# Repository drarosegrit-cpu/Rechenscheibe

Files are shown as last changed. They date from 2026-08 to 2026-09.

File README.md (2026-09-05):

# 🧭 Nautische Rechenscheibe & Taktik-Suite V1.0 – JPK 1080 (*TRUE GRIT*, GER 7447)

Professionelles, analog-digitales Regatta-, Navigations- und Taktiksystem für die Yacht **JPK 1080 (*TRUE GRIT*, GER 7447)**.  
Dieses System verbindet die offiziellen **ORC-VPP-Polardaten** (ORC International / Club, Run-ID `249116`) mit:
1. Einer **doppelseitigen $\varnothing 180\,\text{mm}$ Sandwich-Rechenscheibe** mit integriertem **TackingMaster-Taktikring**, normierten ORC-Polaren (Weg A), echten AWA-Fasskreisbögen und zirkularem Rechenschieber.
2. Einer **vollständigen Fertigungssuite** mit 3D-Druck-Modellen (STL) und hochpräzisen Laser-CAM-Vektordateien (SVG).
3. Einem **digitalen Taktik-Bordcomputer** (`tactical_advisor.py`) mit Einzelsegelanalyse und Isochronen-Routenoptimierer (`route_optimizer.py`).

---

## 📑 Inhaltsverzeichnis
1. [Systemübersicht & Mechanische Architektur (180 mm Sandwich-Kassette)](#-systemübersicht--mechanische-architektur)
2. [Vorderseite (Seite A): Taktikring & Normierte Polaren (Weg A)](#-vorderseite-seite-a-taktikring--normierte-polaren-weg-a)
3. [Rückseite (Seite B): Zirkularer Rechenschieber & Sinus-Skala (S-Skala)](#-rückseite-seite-b-zirkularer-rechenschieber--sinus-skala)
4. [Hardware-Fertigungsanleitung (3D-Druck & Lasergravur)](#-hardware-fertigungsanleitung)
5. [Software-Suite & CLI-Bedienung](#-software-suite--cli-bedienung)
6. [Taktisches Handbuch für den Regatta-Einsatz](#-taktisches-handbuch-für-den-regatta-einsatz)
7. [Dateistruktur des Repositories](#-dateistruktur-des-repositories)

---

## 📐 Systemübersicht & Mechanische Architektur

Die Rechenscheibe basiert auf einem robusten **$\varnothing 180\,\text{mm}$ Sandwich-Kassettensystem**, das für harte Hochsee- und Regattabedingungen im Cockpit entwickelt wurde.

```
                  EXPLOSIONSDARSTELLUNG DER 180 mm KASSETTE
                  
       [ 6x M3 Senkschrauben auf Teilkreis Ø 176 mm ]
                            │
                            ▼
     ┌──────────────────────────────────────────────────────────┐
     │  GEHÄUSE-DECKEL (STATOR VORDERSEITE)                     │  Ø 180 mm
     │  360° Kompassrose graviert · Sichtfenster Ø 150 mm       │  Dicke: 2.2 mm
     └──────────────────────────────────────────────────────────┘
                            │
                            ▼
     ┌──────────────────────────────────────────────────────────┐
     │  MITTELSCHEIBE (DOPPELSEITIGER ROTOR)                    │  Ø 150 mm (Rumpf)
     │  • Seite A: TackingMaster-Taktik & Polaren (Weg A)       │  Ø 172 mm (Führungsfeder)
     │  • Seite B: Log-Skala C & Sinusskala S                   │  Ø 186 mm (4 Daumen-Tabs)
     └──────────────────────────────────────────────────────────┘
                            ▲
                            │  [ Axialspiel: 0.4 mm · Radialspiel: 0.5 mm ]
                            │
     ┌──────────────────────────────────────────────────────────┐
     │  GEHÄUSE-BODEN (STATOR RÜCKSEITE)                        │  Ø 180 mm
     │  Umlaufende Führungsnut (Ø 173 mm x 2.4 mm)              │  Dicke: 4.0 mm
     │  Logarithmische Skala D graviert                         │
     └──────────────────────────────────────────────────────────┘
                            │
                            ▼
     ┌──────────────────────────────────────────────────────────┐
     │  ZENTRALZEIGER & ACHSPIN                                 │  Länge: 85 mm
     │  Acryl-Zeigerarm mit Ratio-Skala · Formschlüssiger Bolzen│  Pin: Ø 3.0 mm
     └──────────────────────────────────────────────────────────┘
```

### Mechanische Spezifikationen
* **Außendurchmesser:** $180.0\,\text{mm}$
* **Sichtfenster / Drehscheiben-Durchmesser:** $150.0\,\text{mm}$
* **Bedienung:** 4 gerändelte Daumen-Tabs an der Drehscheibe (protrudieren auf $\varnothing 186.0\,\text{mm}$, je $15^\circ$ Bogenbreite bei $45^\circ, 135^\circ, 225^\circ, 315^\circ$).
* **Führungssystem:** Feder-Nut-Führung ($\varnothing 172.0\,\text{mm}$ Federring am Rotor greift in $\varnothing 173.0\,\text{mm} \times 2.4\,\text{mm}$ Nut im Boden) – garantiert absolut spielfreien, seidenweichen Lauf ohne Verkanten.
* **Verschraubung:** 6 symmetrische $M3$-Senkkopfschrauben auf Teilkreis $\varnothing 176.0\,\text{mm}$.
* **Zentraler Zeigerarm:** $85\,\text{mm}$ transparenter Acrylzeiger mit radialer roter Peilkante, gravierter Ratio-Skala ($0.0$ bis $1.2$) und Peilspitze zur äußeren Stator-Kompassrose.

---

## ⛵ Vorderseite (Seite A): Taktikring & Normierte Polaren (Weg A)

Die Vorderseite vereint die Funktionalität des bekannten **TackingMaster-Regattarechners** mit den hochpräzisen **ORC-Geschwindigkeitspolaren** der JPK 1080.

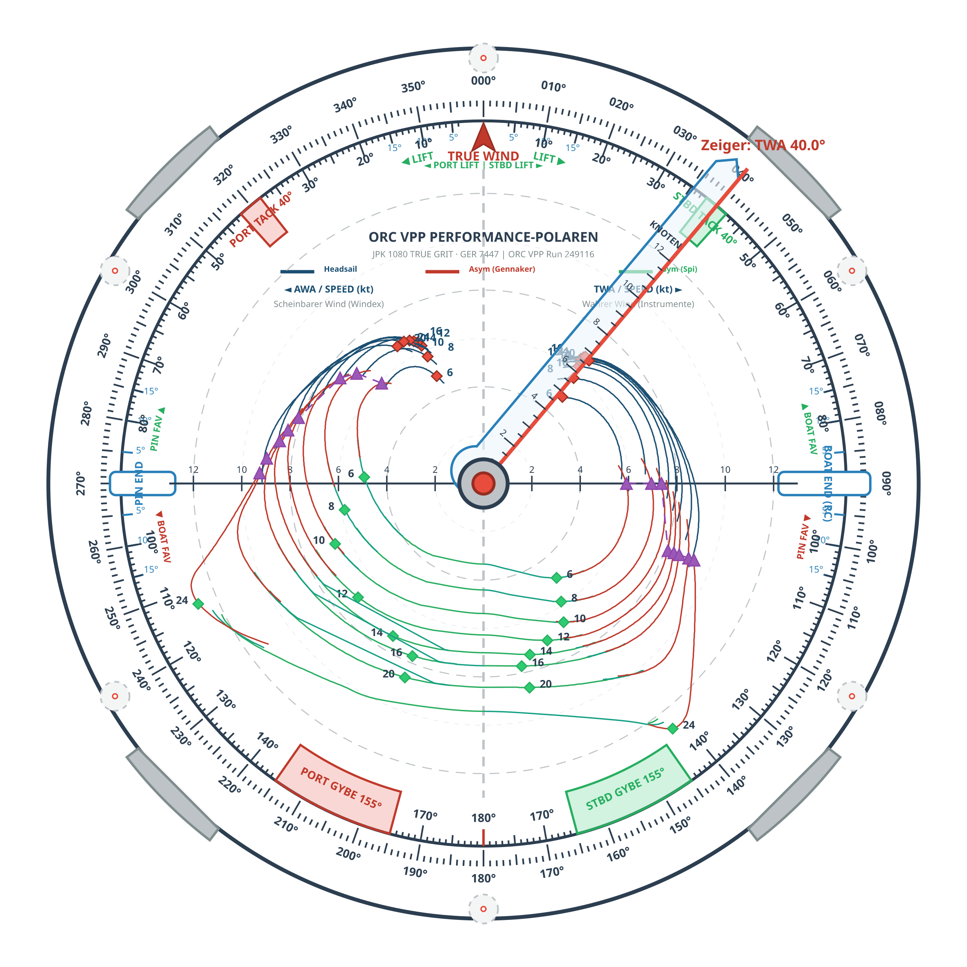
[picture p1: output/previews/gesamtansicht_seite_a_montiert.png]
Montierte Gesamtansicht Seite A


### 1. Der äußere Stator-Kompassring ($\varnothing 150$ bis $\varnothing 180\,\text{mm}$)
* Vollständige **$360^\circ$-Kompassrose** mit $1^\circ$-Feinteilung, $5^\circ$-Teilung und $10^\circ$-Beschriftung.
* Bleibt starr am Gehäuse ausgerichtet; dient zur Peilung von Windrichtung ($TWD$), Kurs über Grund ($COG$) und Landmarken.

### 2. Der integrierte TackingMaster-Taktikring (Rotor-Rand $\varnothing 132$ bis $\varnothing 150\,\text{mm}$)
* **TRUE WIND Index (12 Uhr):** Markanter roter Pfeil zum Ausrichten der Drehscheibe auf die aktuelle Wahre Windrichtung ($TWD$).
* **Winddreher-Skalen (Shift / Lift):**  
  $\pm 5^\circ, \pm 10^\circ, \pm 15^\circ$ Skalierung zu beiden Seiten des Windpfeils. Zeigt sofort, ob ein Winddreher ein **LIFT** (Höhe laufen) oder ein **HEADER** (Abfallen) auf dem aktuellen Bug ist.
* **TACK-Wendewinkel-Sektoren:**  
  Farbcodierte Zonen für Am-Wind-Kurse von **$38^\circ$ bis $42^\circ$** (Grün = Steuerbordbug / Starboard Tack, Rot = Backbordbug / Port Tack). Zeigt direkt den neuen Kurs nach der Wende an.
* **START LINE BIAS System ($\pm 90^\circ$ zur Windachse):**  
  * Eingezeichnete Peilmarken bei $+90^\circ$ (**Boat End / Startschiff**) und $-90^\circ$ (**Pin End / Starttonne**).
  * Bias-Skalen mit $\pm 5^\circ, \pm 10^\circ, \pm 15^\circ$ Abweichung: Ermöglicht die sekundenschnelle Bestimmung des bevorteilten Startlinien-Endes.
* **GYBE-Halsenwinkel-Sektoren:**  
  Farbcodierte Zonen für Vorwind-Kurse von **$145^\circ$ bis $165^\circ$** (Target VMG Gybe Angle bei $155^\circ$).

### 3. Normierte ORC-Geschwindigkeitspolaren (Weg A, $L = 64\,\text{mm}$)
* **Windpol im geometrischen Zentrum $(0,0)$:**  
  Der wahre Windvektor entspringt direkt im Drehpunkt der Scheibe.
* **Basislinie:** Rote Vertikallinie vom Windpol $(0,0)$ nach unten zum Gegenpol $P_1(180^\circ)$ bei $(0, -64\,\text{mm})$.
* **8 Windgeschwindigkeiten:** Kurven für $6, 8, 10, 12, 14, 16, 20, 24\,\text{kt}$ True Wind Speed ($TWS$).
* **Physikalische Normierung:** Der Radius entspricht dem Geschwindigkeitsverhältnis $\text{Ratio} = \frac{V_{BS}}{TWS}$.
* **VMG-Targets:**  
  * Rote Rauten: Optimale Am-Wind-Punkte ($VMG_{upwind}$ Beat Angles zwischen $42.3^\circ$ und $40.7^\circ$).
  * Grüne Rauten: Optimale Vorwind-Punkte ($VMG_{downwind}$ Run Angles zwischen $142^\circ$ und $165^\circ$).
* **Segel-Crossover (Jib vs. Asymmetrischer Gennaker):**  
  Violette Dreiecke und gestrichelte Grenzlinie markieren exakt den wahren Windwinkel ($TWA$), bei dem das Setzen des Gennakers schneller ist als die Genua/Fock.
* **Echte AWA-Fasskreisbögen:**  
  Kreisbögen durch Windpol $(0,0)$ und $P_1(180^\circ)$ für $AWA = 25^\circ, 30^\circ, 35^\circ, 40^\circ, 45^\circ, 50^\circ, 60^\circ, 75^\circ, 90^\circ, 110^\circ, 135^\circ, 155^\circ$. Ermöglichen die sofortige Ablesung des scheinbaren Windes ohne Vektorkonstruktion.

---

## 🔢 Rückseite (Seite B): Zirkularer Rechenschieber & Sinus-Skala

Die Rückseite verwandelt die Rechenscheibe in einen hochpräzisen Navigationsrechner zur Lösung von Multiplikation, Division, Weg-Zeit-Geschwindigkeit und Winddreiecks-Trigonometrie.

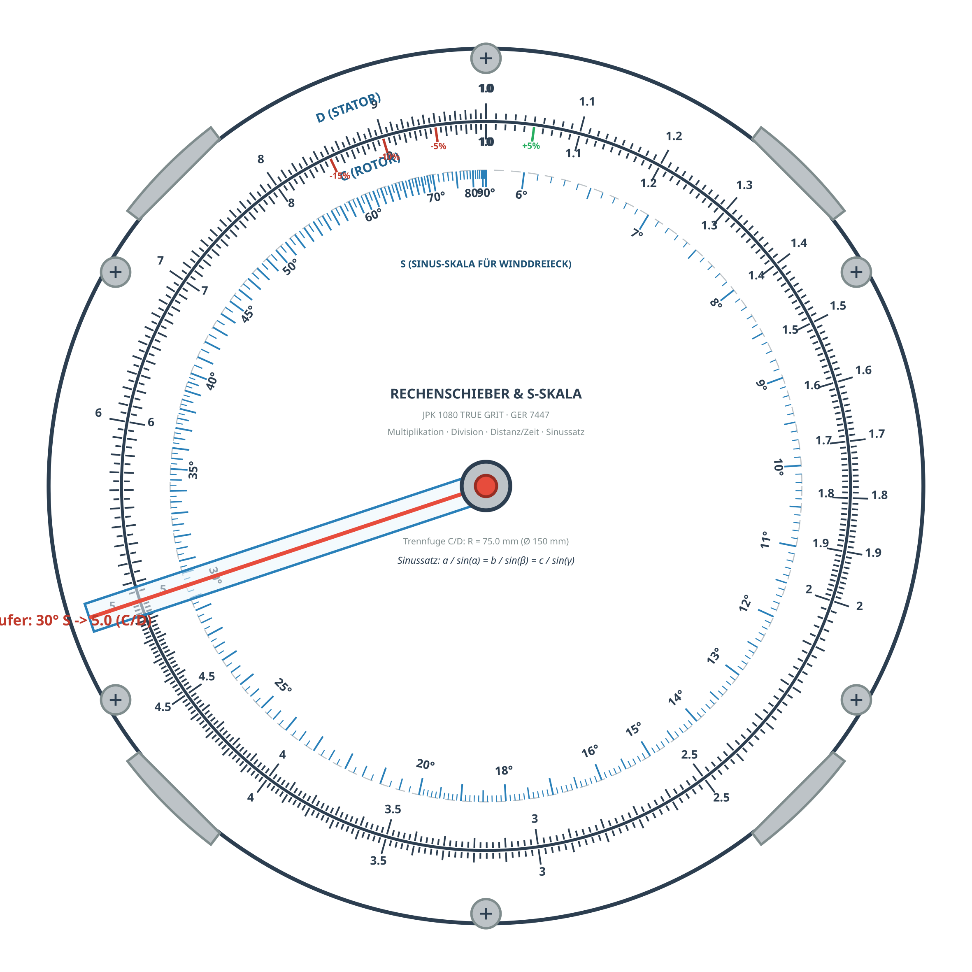
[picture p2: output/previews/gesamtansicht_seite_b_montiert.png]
Montierte Gesamtansicht Seite B


### 1. Die Skalenanordnung
* **D-Skala (Stator / Fester Außenring):**  
  Logarithmische Grundskala von $1.0$ bis $10.0$ entlang des Radius $75.5\,\text{mm}$ bis $82.0\,\text{mm}$.
* **C-Skala (Rotor / Drehscheibe):**  
  Identische logarithmische Skala von $1.0$ bis $10.0$ entlang des Radius $74.5\,\text{mm}$ nach innen.
* **Haarfeine Trennfuge bei $R = 75.0\,\text{mm}$:**  
  C- und D-Skala gleiten unmittelbar aneinander vorbei, was parallaxenfreies Ablesen ermöglicht.
* **S-Skala (Sinusskala bei $R = 48.0\,\text{mm}$):**  
  Logarithmische Teilung für Winkel von $6^\circ$ bis $90^\circ$ gemäss $\theta = 360^\circ \cdot \log_{10}(10 \cdot \sin\alpha)$.
* **Performance-Nonius (bei der $1.0$-Marke):**  
  Farbige Marken für $-15\%, -10\%, -5\%$ (Rot) und $+5\%$ (Grün) erlauben den schnellen Soll/Ist-Vergleich der Bootsgeschwindigkeit.

### 2. Rechenbeispiele

#### A. Bootsgeschwindigkeit aus Ratio berechnen ($\text{Ratio} \times TWS = V_{BS}$)
1. Lies auf Seite A an der Zeigerkante die Ratio ab (z. B. **$0.54$** bei $16\,\text{kt}$ Wind auf $TWA = 110^\circ$).
2. Drehe die Scheibe um: Stelle die **$1.0$** der C-Skala (Rotor) auf die **$0.54$** (bzw. $5.4$) der D-Skala (Stator).
3. Suche auf der C-Skala den Windwert **$1.6$** ($16\,\text{kt}$).
4. Lies auf der D-Skala direkt das Ergebnis ab: **$8.64\,\text{kt}$** Targets-Speed!

#### B. Distanz- und Fahrzeitberechnung ($\text{Distanz} = \text{Speed} \times \text{Zeit}$)
* Stelle die $1.0$ auf die Bootsgeschwindigkeit in Knoten.
* Lies für jede Fahrzeit in Stunden (C-Skala) direkt die Seemeilen (D-Skala) ab.

#### C. Lösung des Winddreiecks über die S-Skala (Sinussatz)
Im Winddreieck gilt:
$$\frac{V_{BS}}{\sin(\delta)} = \frac{AWS}{\sin(TWA)} = \frac{TWS}{\sin(AWA)}$$
Durch Kopplung der Sinusskala mit den logarithmischen Skalen lassen sich scheinbarer Windwinkel ($AWA$) und wahrer Windwinkel ($TWA$) rein mechanisch ineinander umrechnen.

---

## 🛠️ Hardware-Fertigungsanleitung

Alle Fertigungsdateien wurden mit sub-millimetergenauen Toleranzen erzeugt.

### 1. 3D-Druck (Dateien in `output/stl/`)

| Dateiname | Bauteil | Abmessungen | Empfohlenes Material |
| :--- | :--- | :--- | :--- |
| [`gehaeuse_deckel_180mm.stl`](output/stl/gehaeuse_deckel_180mm.stl) | Gehäuse-Deckel (Stator A) | $\varnothing 180 \times 2.2\,\text{mm}$, Fenster $\varnothing 150\,\text{mm}$ | PETG / ASA / PLA-CF |
| [`gehaeuse_boden_180mm.stl`](output/stl/gehaeuse_boden_180mm.stl) | Gehäuse-Boden (Stator B) | $\varnothing 180 \times 4.0\,\text{mm}$, Nut $\varnothing 173 \times 2.4\,\text{mm}$ | PETG / ASA / PLA-CF |
| [`mittelscheibe_rotor_180mm.stl`](output/stl/mittelscheibe_rotor_180mm.stl) | Rotor-Drehscheibe | $\varnothing 150/\varnothing 172/\varnothing 186 \times 2.0\,\text{mm}$ | PETG / Weiß matt |
| [`zentralzeiger_lineal.stl`](output/stl/zentralzeiger_lineal.stl) | Peilzeiger | Länge $85\,\text{mm}$, Breite $7\,\text{mm}$, Dicke $1.5\,\text{mm}$ | Transparentes PETG / Resin |
| [`achspin_mittelbolzen.stl`](output/stl/achspin_mittelbolzen.stl) | Zentraler Achsbolzen | Schaft $\varnothing 3.0 \times 7.2\,\text{mm}$, Kopf $\varnothing 9.0\,\text{mm}$ | PETG / Nylon / Messing |

#### Druckparameter-Empfehlung
* **Schichthöhe:** $0.12\,\text{mm}$ bis $0.16\,\text{mm}$
* **Wandlinien (Perimeters):** Mindestens 4 Linien
* **Infill:** $100\%$ für verzugsfreie Planlage
* **Oberflächen-Glätten (Ironing):** Auf allen Deckschichten aktivieren, um eine spiegelglatte Basis für die Skalengravur zu erhalten.

### 2. Laserschneiden & Vektorgravur (Dateien in `output/svg/`)

Die SVG-Dateien sind 1:1 im Millimeter-Maßstab für moderne CAM- und Lasersoftware (LightBurn, RDWorks, Glowforge, Trotec JobControl) vorbereitet:

| Dateiname | Funktion | Farben & Ebenen |
| :--- | :--- | :--- |
| [`laser_seite_a_rotor_vorderseite.svg`](output/svg/laser_seite_a_rotor_vorderseite.svg) | Front Rotor (Polaren & Taktik) | Rot = Schnitt, Schwarz/Farbig = Gravur |
| [`laser_seite_a_deckel_kompassrose.svg`](output/svg/laser_seite_a_deckel_kompassrose.svg) | Stator Deckel ($360^\circ$ Rose) | Rot = Schnitt (Ring & 6x M3), Schwarz = Gravur |
| [`laser_seite_b_rotor_rueckseite.svg`](output/svg/laser_seite_b_rotor_rueckseite.svg) | Back Rotor (C- & S-Skala) | Rot = Schnitt, Schwarz = Gravur |
| [`laser_seite_b_boden_d_skala.svg`](output/svg/laser_seite_b_boden_d_skala.svg) | Stator Boden (D-Skala) | Rot = Schnitt (Ring & 6x M3), Schwarz = Gravur |
| [`laser_zentralzeiger.svg`](output/svg/laser_zentralzeiger.svg) | Acryl-Zeigerarm mit Skala | Rot = Konturschnitt, Schwarz = Ratio-Teilung |

#### Laser-Farbstandard
* **Rot (`#FF0000`, Strichstärke $0.15\,\text{mm}$):** Vektorschnitt (Cut Lines).
* **Schwarz (`#000000`, Strichstärke $0.25\,\text{mm}$):** Feine Vektorgravur (Skalenstriche & Beschriftungen).
* **Buntfarben:** Akzent-Gravuren (Grün `#27AE60`, Rot `#C0392B`, Blau `#2980B9`, Violett `#8E44AD`).

---

## 💻 Software-Suite & CLI-Bedienung

### 1. Alles auf Knopfdruck generieren
```bash
python3 rechenscheibe.py --all
```
Erzeugt alle 5 STL-Dateien, alle 5 SVG-Laserdateien und alle hochauflösenden 300-DPI-PNG-Vorschauen in einem einzigen Durchlauf.

### 2. Gezielte Einzelausführung
```bash
# Nur 3D-Druck-Modelle erzeugen
python3 rechenscheibe.py --stl

# Nur Laser-SVG-Dateien erzeugen
python3 rechenscheibe.py --svg

# Vorschau mit benutzerdefiniertem Zeigerwinkel rendern (z. B. TWA 65°)
python3 rechenscheibe.py --preview --twa 65.0 --dpi 300
```

### 3. Taktischer Regattacomputer (`tactical_advisor.py`)
```bash
python3 tactical_advisor.py --hdg 215 --twd 340 --tws 14
```
Berechnet Soll-Bootsgeschwindigkeit, Krängungswinkel und Segelvergleich (Jib vs. Gennaker) für die eingegebenen Umweltbedingungen.

### 4. Regattakurs-Optimierer (`route_optimizer.py`)
```bash
python3 route_optimizer.py --gpx data/Kursdaten.gpx --twd 340 --tws 14
```

---

## 🏁 Taktisches Handbuch für den Regatta-Einsatz

### Phase 1: Vor dem Start (Startlinien-Bias)
1. Fahre die Startlinie entlang oder peile die Linie mit dem Handpeilkompass (z. B. Kurs $075^\circ$ von Pin zu Schiff).
2. Drehe den Rotor so, dass der rote **TRUE WIND Pfeil** auf die vor dem Start gemessene mittlere Windrichtung ($TWD$, z. B. $345^\circ$) auf der Gehäuse-Kompassrose zeigt.
3. Blicke auf die Markierungen **BOAT END** ($+90^\circ$) und **PIN END** ($-90^\circ$):
   * Liegt die gepeilte Startlinie im Bereich **▲ BOAT FAV**, ist das Startschiff bevorteilt $\rightarrow$ Start am Schiff bringt einen Luv-Vorsprung.
   * Liegt sie im Bereich **PIN FAV ▲**, ist die Starttonne bevorteilt $\rightarrow$ Start an der Tonne bringt sofortigen Raumgewinn.
   * Die Skala ($5^\circ, 10^\circ, 15^\circ$) quantifiziert den Längen-Vorteil direkt in Metern pro 100 m Linienlänge!

### Phase 2: Am-Wind-Schlag (Upwind Beat & Shifts)
1. Richte die Scheibe auf den gemittelten Grundwind aus.
2. Der optimale Am-Wind-Winkel liegt in den grünen/roten **TACK Sectors ($38^\circ$ bis $42^\circ$)**.
3. **Winddreher ausnutzen:**
   * Dreht der Wind nach rechts $\rightarrow$ Auf Steuerbordbug zeigt die Skala **STBD LIFT** $\rightarrow$ Du kannst höher anluven!
   * Dreht der Wind nach links $\rightarrow$ Auf Steuerbordbug zeigt die Skala **HEADER** $\rightarrow$ Wendesignal! Nach der Wende auf Backbordbug bist du im **PORT LIFT**.
4. **Target Speed kontrollieren:**  
   Lege den Zeiger auf $40^\circ$. Lies an der roten Raute der aktuellen Windstärke deine Soll-Geschwindigkeit ab. Erreichst du sie nicht, trimme die Segel oder kontrolliere den Rudergänger!

### Phase 3: Segelwechsel am Crossover
* Am Wind und auf leichtem Raumkurs führt der Zeiger über die Polaren.
* Sobald der Zeiger die **violette Crossover-Linie** überschreitet, überholt das asymmetrische Spi-Polare die Genua-Kurve:
  * Unterhalb der Crossover-Linie: Fock/Genua fahren.
  * Oberhalb der Crossover-Linie: Gennaker setzen!

### Phase 4: Vorwind-Schenkel (Downwind VMG)
* Auf dem Spikurs liegt das optimale Ziel nicht auf direktem Vorwindkurs ($180^\circ$), sondern in den **GYBE Sectors ($145^\circ$ bis $165^\circ$)**, markiert durch die grünen VMG-Rauten.
* Steuere exakt diesen Target-Winkel, um das maximale $VMG_{downwind}$ zu erzielen.

---

## 📁 Dateistruktur des Repositories

```
Rechenscheibe/
├── rechenscheibe.py             # Master CLI Orchestrator (V1.0 Software Suite)
├── vector_engine.py             # CAM / Laser SVG Vektorgrafik-Generator (1:1 CAD)
├── stl_generator.py             # 3D-Druck STL Mesh Generator (Wasserdichte Volumenkörper)
├── preview_engine.py            # 300 DPI High-Resolution Visual Rendering Engine
├── polar_parser.py              # ORC SLK/CSV Parser & Catmull-Rom Spline Interpolator
├── tactical_advisor.py          # Taktischer Digital-Bordcomputer für die JPK 1080
├── route_optimizer.py           # Regattakurs- und Isochronen-Routenplaner
├── orc_extractor.py             # PDF/Text Extrahierung für ORC Speed Guides
├── config_manager.py            # Geometrie- & Toleranzmanager
├── config.json                  # Zentrale Parameter- & Toleranzdatei
│
├── data/
│   ├── 249116.slk               # Offizielle ORC VPP Polardaten JPK 1080 (TRUE GRIT)
│   └── Kursdaten.gpx            # Beispiel-Regattakurs (Rund Fyn / Ostsee)
│
├── output/
│   ├── stl/                     # Druckfertige 3D-Modelle
│   │   ├── gehaeuse_deckel_180mm.stl
│   │   ├── gehaeuse_boden_180mm.stl
│   │   ├── mittelscheibe_rotor_180mm.stl
│   │   ├── zentralzeiger_lineal.stl
│   │   └── achspin_mittelbolzen.stl
│   ├── svg/                     # Fertigungsgerechte Laser-Zuschnitt- & Gravurdateien
│   │   ├── laser_seite_a_rotor_vorderseite.svg
│   │   ├── laser_seite_a_deckel_kompassrose.svg
│   │   ├── laser_seite_b_rotor_rueckseite.svg
│   │   ├── laser_seite_b_boden_d_skala.svg
│   │   └── laser_zentralzeiger.svg
│   └── previews/                # 300 DPI hochauflösende Visualisierungen
│       ├── gesamtansicht_seite_a_montiert.png
│       ├── gesamtansicht_seite_b_montiert.png
│       └── rotor_vorderseite_weg_a.png
│
└── _archive/                    # Revisionssicheres Archiv aller Zwischenstände (Regel 3)
```

---

## 🏆 Projektdaten & Impressum
* **Yacht:** JPK 1080 *TRUE GRIT* (GER 7447)
* **ORC Zertifikat:** 2025 / 2026 (VPP Run 249116)
* **Version:** 1.0 (Freigabe erteilt)
* **Lizenz:** Open Source für die Hochsee-Regatta-Community

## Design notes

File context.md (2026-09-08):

# 🧭 Projekthistorie & Statusdokumentation: Nautische Rechenscheibe V3.0
**Yacht:** JPK 1080 (*TRUE GRIT*, GER 7447)  
**Datum:** 08. September 2026  
**Status:** Release V3.0 fertiggestellt, validiert & auf Git synchronisiert (`origin/main`)

---

## 1. Projektübersicht & Kernarchitektur
Entwicklung einer professionellen, doppelseitigen **Ø 180 mm Sandwich-Rechenscheibe** für Regattaeinsatz, Taktik und Hochseenavigation im Cockpit:
- **Seite A (Vorderseite):** TackingMaster-Taktikring (Winddreher, Tack/Gybe-Sektoren, Startlinien-Bias) kombiniert mit **1:1 ORC-VPP-Polaren** in absoluten Knoten (5,0 mm/kn, R_max = 65,0 mm für 13,0 kn). Asymmetrische Darstellung: Steuerbord (TWA) zum Steuern nach Instrumenten, Backbord (AWA) zum Steuern nach Windex/Verklicker.
- **Seite B (Rückseite):** Zirkularer Rechenschieber (C- und D-Skala) für Distanz-Zeit-Geschwindigkeit sowie eine exakt radial ausgerichtete Sinusskala (S-Skala bei R = 65,0 mm) für Winddreiecks-Trigonometrie samt transparentem Läufer.
- **Parametrisches Framework:** Single Source of Truth über `config.json` und `config_manager.py`. Sämtliche Dimensionen, Toleranzen, Schichtfarben und Beschriftungen werden mathematisch konsistent abgeleitet.
- **Fertigung:** Wasserdichte 3D-Druck-Komponenten (Bambu Lab) und hochpräzise Laser-Vektordateien (SVG) mit identischen 300-DPI-Vorschauen (`librsvg`/`libcairo`).

---

## 2. Abgeschlossene Meilensteine (Session 08.09.2026)

### A. Mechanik & 3D-Druck-Optimierung (Bambu Lab)
- **1,0 mm Zentrierbohrungen für M3-Verschraubung:**  
  Auf dem Teilkreis R = 88,0 mm (Ø 176,0 mm) wurden im Gehäusedeckel und Gehäuseboden jeweils 6 symmetrische 1,0 mm Zentrierbohrungen integriert (als Vorbohr- und Ausrichthilfe für 3D-Druck und Laserschnitt).
- **100% 2-Manifold Geometrien:**  
  Alle 6 STL-Dateien (`mesh_generator.py`) sind absolut wasserdicht (0 Non-Manifold Kanten, 0 Selbstüberschneidungen) und slicen fehlerfrei in Bambu Studio und OrcaSlicer.

### B. Bereinigung & Zentralisierte Konfiguration
- **Entfernung von Entwicklungsrelikten:**  
  Entfernung aller temporären Beschriftungen wie „1:1 Knoten“ und „Rückseite“.
- **Zentrale Labels & Pfade:**  
  Alle Titel, Untertitel, Skalenbeschriftungen sowie der Pfad zum Speed Guide (`speedguide_file`) werden zentral über `config.json` verwaltet.

### C. Nahtloser 180°-Polarenübergang & Behebung des Speed-Guide-Versatzes
- **Ursachenanalyse im ORC Speed Guide:**  
  1. Die HTML-Vorlage trennt TWA (rechts, Ursprung X=1077) und AWA (links, Ursprung X=1023) durch eine 54-Pixel-Lücke (ca. 0,72 kn Buchfalz-Versatz).  
  2. Die getrimmten Segelkurven endeten vorzeitig bei optimalen Halsenwinkeln (145° bis 165°).
- **Vektortrigonometrische Korrektur:**  
  Umstellung von `calc_wind_triangle_awa` auf Vektor-`atan2(x, y)` (`x = TWS * sin(TWA)`, `y = TWS * cos(TWA) + BSP`) zur fehlerfreien Abbildung des vollen Bereichs von 0° bis 180° (`AWA = 180,0°` bei `TWA = 180,0°`).
- **Vorwind-Fortführung (`_extend_downwind_to_180`):**  
  Fortführung der tiefsten Vorwind-Segmente über die realen ORC-VPP-Stützstellen (150°, 165°, 180°) aus `249116.slk` bis zum gemeinsamen 180°-Punkt `(0, V_BS(180°))`.
- **Horizontale Tangente (C1-Stetigkeit):**  
  Virtuelle Spiegelpunkte `(-x, y)` am Scheitelpunkt erzwingen `dy/dx = 0` bei `X = 0`, wodurch die Kurven völlig knick- und kantenfrei von Steuerbord nach Backbord ineinander übergehen.
- **Mathematische Verifikation:**  
  Fehler an allen 8 Windstärken (6 bis 24 kn) beträgt exakt 0,000 mm:
  - 6 kn TWS -> 3,33 kn V_BS (Y = 16,67 mm)
  - 8 kn TWS -> 4,40 kn V_BS (Y = 22,01 mm)
  - 10 kn TWS -> 5,38 kn V_BS (Y = 26,89 mm)
  - 12 kn TWS -> 6,26 kn V_BS (Y = 31,32 mm)
  - 14 kn TWS -> 7,00 kn V_BS (Y = 35,00 mm)
  - 16 kn TWS -> 7,54 kn V_BS (Y = 37,69 mm)
  - 20 kn TWS -> 8,43 kn V_BS (Y = 42,15 mm)
  - 24 kn TWS -> 9,42 kn V_BS (Y = 47,12 mm)

### D. Dokumentation & Git-Status
- `README.md` vollständig auf Stand Release V3.0 aktualisiert.
- Alle STLs, SVGs und 300-DPI-PNGs neu gerendert.
- Alle Änderungen committet und auf GitHub gepusht (Commit `ab468ea`).

---

## 3. Dateistruktur & Wichtige Pfade
- **Steuerung & CLI:** [`rechenscheibe.py`](rechenscheibe.py)
- **Konfiguration:** [`config.json`](config.json), [`config_manager.py`](config_manager.py)
- **Vektor- & Polarmodelle:** [`polar_parser.py`](polar_parser.py), [`vector_engine.py`](vector_engine.py)
- **3D-Mesh-Generator:** [`mesh_generator.py`](mesh_generator.py)
- **Eingangsdaten:** [`data/249116.slk`](data/249116.slk), [`data/ORC_SpeedGuide_TRUE_GRIT_27.12.2025.html`](data/ORC_SpeedGuide_TRUE_GRIT_27.12.2025.html)
- **Fertigungsdateien (`output/`):**
  - `stl/`: 6 wasserdichte STL-Dateien (Gehäusedeckel, Gehäuseboden, Mittelscheibe, Zeiger, Achspin)
  - `svg/`: 8 fertigungsgerechte Laser-Vektordateien
  - `previews/`: Hochauflösende 300-DPI-PNG-Vorschauen
- **Versionssicherung:** `_archive/` (strikte zweistellige fortlaufende Nummerierung)

---

## 4. Nächste Schritte für die kommende Session
1. **Druckvorbereitung:** Probe-Import der STL-Dateien in Bambu Studio zur Prüfung der Wandstärken, Toleranzen und Stützstrukturen.
2. **Laserschneider-Setup:** Zuweisung der RGB-Farblinien (Gravur vs. Schnitt) für zweifarbiges Acryl / Rowmark.
3. **Hardware-Montage:** Prüfung von Schraubenlängen (M3 x 8 mm Senkkopf) und Achsbolzenspiel.

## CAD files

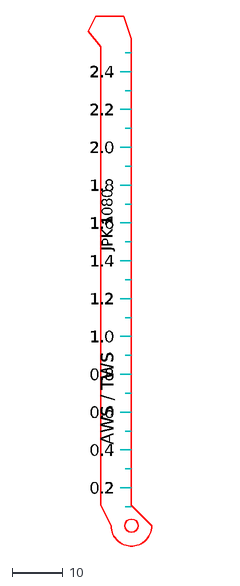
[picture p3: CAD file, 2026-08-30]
output/laser_lineal.dxf
0.2
0.4
0.6
0.8
1.0
1.2
1.4
1.6
1.8
2.0
2.2
2.4
AWS / TWS
JPK 1080

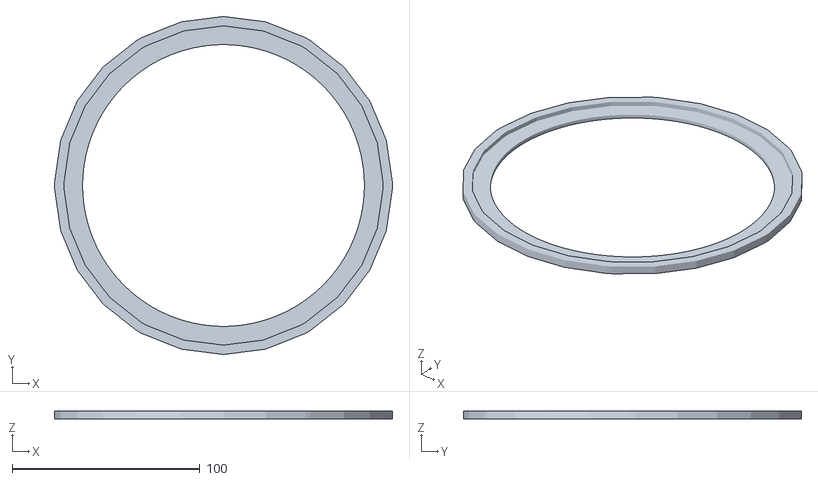
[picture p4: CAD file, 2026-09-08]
output/stl/gehaeuse_boden_180mm.stl
180.0 x 180.0 x 4.40

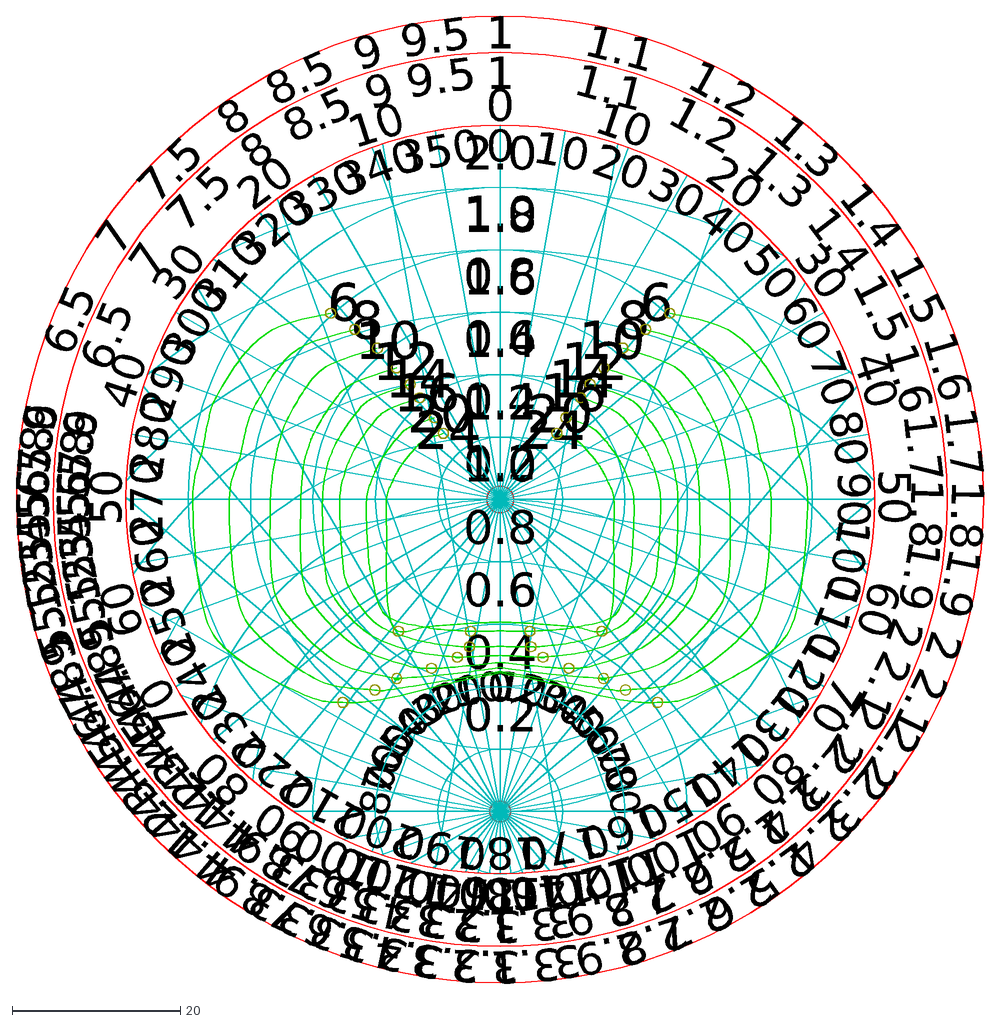
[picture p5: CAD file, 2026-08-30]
output/laser_rotor_drehscheibe.dxf
0.2
0.4
0.6
0.8
1.0
0
10
20
30
40
50
60
70
80
1.2
1.4
1.6
1.8
2.0
6
8
12
14
16
24
90
100
110
120
130
140
150
160
170
180
190
200
210
220
230
240
250
260
270
280
290
300
310
320
330
340
350
1
1.1
1.3
1.5
1.7
1.9
2
2.1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

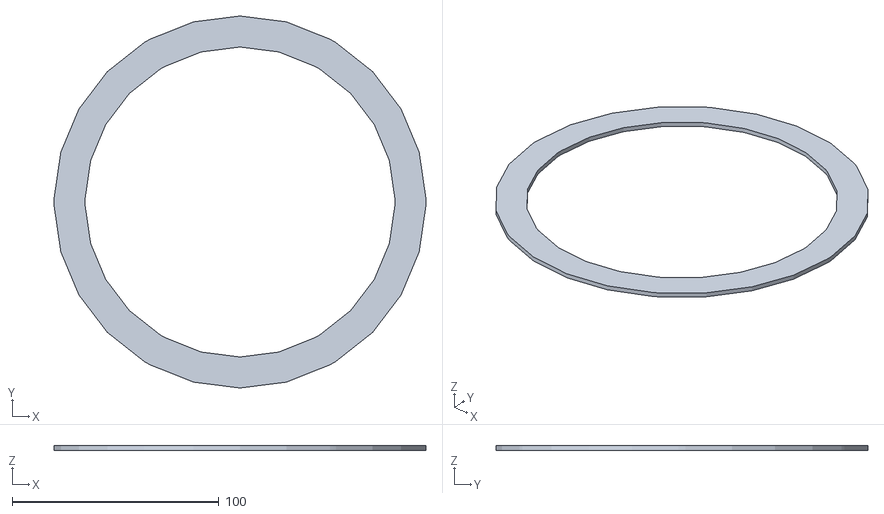
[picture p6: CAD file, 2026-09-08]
output/stl/gehaeuse_deckel_180mm.stl
180.0 x 180.0 x 2.20

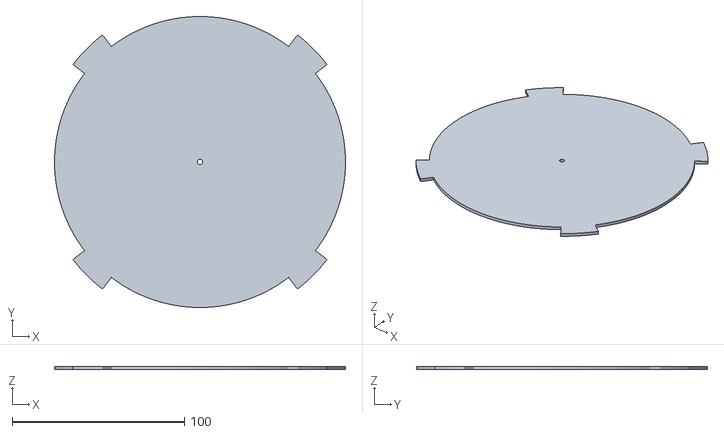
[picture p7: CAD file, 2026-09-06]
output/stl/mittelscheibe_rotor_180mm.stl
169.0 x 169.0 x 2.00

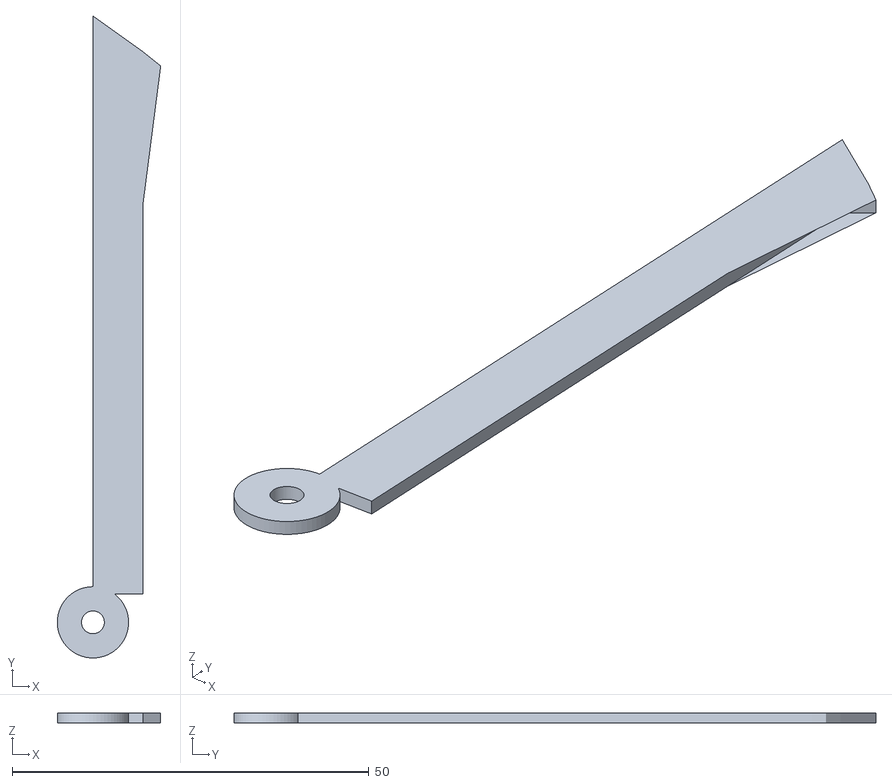
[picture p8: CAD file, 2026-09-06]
output/stl/zentralzeiger_lineal.stl
14.5 x 90.0 x 1.40

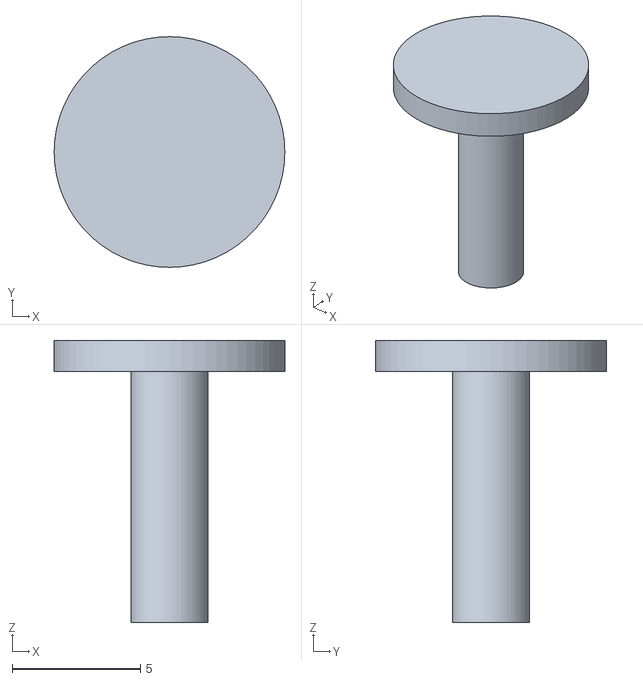
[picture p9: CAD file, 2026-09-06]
output/stl/achspin_mittelbolzen.stl
9.00 x 9.00 x 11.0

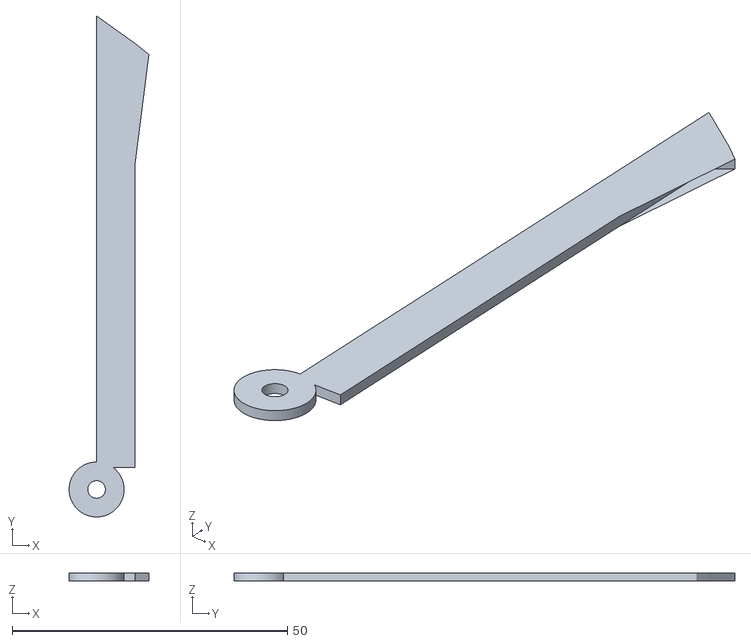
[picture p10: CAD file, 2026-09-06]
output/stl/zentralzeiger_rueckseite.stl
14.5 x 91.0 x 1.40

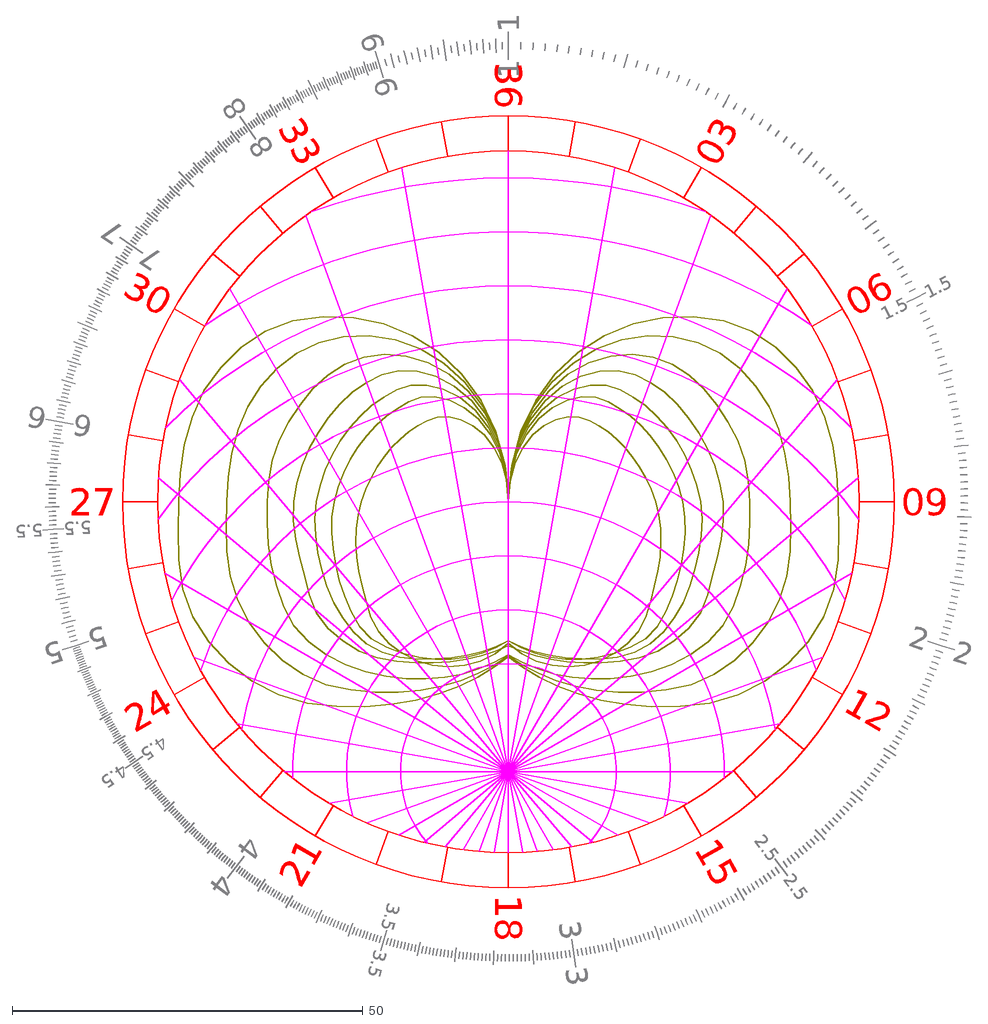
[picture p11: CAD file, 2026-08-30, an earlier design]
_archive/rechenscheibe_neu.dxf
1.5
2
2.5
3
3.5
4
4.5
5
5.5
6
7
8
9
1
18
15
12
09
06
03
36
33
30
27
24
21

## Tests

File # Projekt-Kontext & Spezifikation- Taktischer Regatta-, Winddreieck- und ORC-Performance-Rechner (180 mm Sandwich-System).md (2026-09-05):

# Projekt-Kontext & Spezifikation: Taktischer Regatta-, Winddreieck- und ORC-Performance-Rechner (180 mm Sandwich-System)
## 1. Executive Summary & Zielsetzung
Ziel ist die Realisierung eines physischen, taktischen Segel- und Trimmrechners für Regatten. Das Instrument kombiniert:
1. **Einen taktischen Regattarechner** (Kompassrose vs. wahre Windrichtung mit optimalen Wende- und Halsewinkeln).
2. **Ein Fasskreis-Nomogramm** zur direkten geometrischen Lösung des scheinbaren Winddreiecks ($\alpha = \text{AWA}$) über einer festen Sehne.
3. **Ein ORC-Polardiagramm** der Ziel-Bootsgeschwindigkeiten für eine J/125 (aus hinterlegten Messbriefdaten).
4. **Einen doppelseitig gekoppelten Rechenschieber** (C/D-Geschwindigkeitsskala und Performance-%-Nonius) auf der Rückseite.
Das Gesamtsystem wird dreilagig aufgebaut (Boden, Rotor, Deckel), im 3D-Druck (FDM/SLA) gefertigt und mit einem Laserplotter beschriftet/graviert.
---
## 2. Mechanische Architektur & Toleranzen
### 2.1 Führungskonzept (Nut-und-Feder Kassettenführung)
* **Zentraler Verzicht:** Keine zentrale Achsschraube/Mittelbolzen, um den Innenbereich für Kurven und geometrische Konstruktionen vollkommen plan und ablesbar zu halten.
* **Führung:** Die drehbare Mittelscheibe (Rotor) besitzt einen umlaufenden Außenbund (Feder), der formschlüssig in einer Ringnut zwischen Gehäusedeckel und Gehäuseboden geführt wird.
* **Bedienung:** Vier symmetrisch angeordnete Rändelsegmente ragen radial aus dem Gehäuse hervor, um ein feinfühliges Drehen mit Daumen und Fingern (auch mit Handschuhen) zu ermöglichen.
### 2.2 Bauteildimensionierung (System 180 mm)
* **Gehäusedeckel (Seite A / Vorderseite - fest):**
  * Außendurchmesser: $180{,}0\,\text{mm}$
  * Innenfenster (Sichtbereich): $\varnothing 150{,}0\,\text{mm}$
  * Fester Skalensteg: Breite $15{,}0\,\text{mm}$
  * Bauteildicke: $2{,}5\,\text{mm}$
  * Befestigung: 6 Senkbohrungen M3 auf Teilkreis $\varnothing 176{,}0\,\text{mm}$
* **Gehäuseboden (Seite B / Rückseite - fest):**
  * Außendurchmesser: $180{,}0\,\text{mm}$
  * Innenfenster (Sichtbereich): $\varnothing 150{,}0\,\text{mm}$
  * Ringnut: Innendurchmesser $173{,}0\,\text{mm}$, Nuttiefe in Z-Richtung $2{,}4\,\text{mm}$
  * Bauteildicke: $4{,}4\,\text{mm}$ gesamt ($2{,}0\,\text{mm}$ Bodensteg + $2{,}4\,\text{mm}$ Nutring)
  * Befestigung: 6 Bohrungen M3 auf Teilkreis $\varnothing 176{,}0\,\text{mm}$ (für Einschmelzgewinde oder Durchgangsmuttern)
* **Mittelscheibe / Rotor (drehbar, beidseitig opak beschriftbar):**
  * Sichtbarer Bereich (beidseitig): $\varnothing 150{,}0\,\text{mm}$
  * Führungsbund (Feder): $\varnothing 172{,}0\,\text{mm}$, Dicke $2{,}0\,\text{mm}$ (Z-Lage: $0{,}2\,\text{mm}$ bis $2{,}2\,\text{mm}$)
  * 4 Rändelsegmente: Breite je $30^\circ$, Außenradius $93{,}0\,\text{mm}$ ($\varnothing 186{,}0\,\text{mm}$, $3{,}0\,\text{mm}$ Greifüberstand)
* **Fertigungstoleranzen:**
  * Radiales Spiel: $\Delta r = 0{,}5\,\text{mm}$ ($173{,}0\,\text{mm}$ Nut vs. $172{,}0\,\text{mm}$ Bund)
  * Axiales Spiel: $\Delta z = 0{,}4\,\text{mm}$ ($2{,}4\,\text{mm}$ Nut vs. $2{,}0\,\text{mm}$ Bund)
  * Vertiefte Gravurzonen: $0{,}4\,\text{mm}$ plane Absenkung zum Schutz der Lasermarkierung gegen Reibverschleiß
---
## 3. Mathematische Geometrie & Skalen-Architektur
### 3.1 Das Winddreieck
$$\vec{v}_{\text{scheinbar}} = \vec{v}_{\text{wahr}} - \vec{v}_{\text{Boot}} \iff \vec{v}_{\text{wahr}} = \vec{v}_{\text{Boot}} + \vec{v}_{\text{scheinbar}}$$
* $\text{SOG}$: Bootsgeschwindigkeit über Grund
* $\text{AWS}$: Scheinbare Windgeschwindigkeit (Apparent Wind Speed)
* $\alpha = \text{AWA}$: Scheinbarer Windwinkel (Windfahne an Mastspitze)
* $\text{TWS}$: Wahre Windgeschwindigkeit (True Wind Speed)
* $\text{TWA}$: Wahrer Windwinkel (True Wind Angle)
### 3.2 Fasskreis-Nomogramm (Weg A, Option 2: Feste Sehne über wahrem Wind)
* **Basissehne:** Wahre Windrichtung als vertikaler Vektor von $(0,0)$ nach $(0, L)$ auf der Nordachse ($L = 50{,}0\,\text{mm}$).
* **Peripheriewinkelsatz:** Alle Bootspositionen mit scheinbarem Windwinkel $\alpha$ liegen auf einem Kreis über der Basis $L$:
  * **Radius:** $R_\alpha = \frac{L}{2 \sin(\alpha)}$
  * **Mittelpunkt:** $x_M = \pm \frac{L}{2} \cot(\alpha), \quad y_M = \frac{L}{2}$ ($+$ für Steuerbord, $-$ für Backbord)
  * **Auflösung:** Kurvenschar von $\alpha = 20^\circ$ bis $150^\circ$ mit Schrittweite $\Delta\alpha = 2{,}5^\circ$
### 3.3 Logarithmische Rechenskalen (Seite B)
Winkelabbildung über vollen Kreis ($360^\circ$ pro Dekade):
* **Geschwindigkeit (C/D):** $\varphi_v = 360^\circ \cdot \log_{10}(v)$
* **Sinus-Skala (S):** $\varphi_\theta = 360^\circ \cdot \log_{10}(\sin(\theta))$ für $\theta \in [6^\circ, 90^\circ]$
* **Performance-%:** $\Delta\varphi = 360^\circ \cdot \log_{10}(1 + \text{Prozent}/100)$
---
## 4. Gravur- & Skalenbelegung
### Seite A: Taktik-, Fasskreis- & Polartrimm-Rechner (Vorderseite)
1. **Fester Gehäusedeckel (Außenring Ø 150 bis 180 mm):**
   * Vollständige $360^\circ$-Kompassrose mit $1^\circ$-Teilung, beziffert alle $30^\circ$.
2. **Mittelscheibe / Rotor (Sichtfenster Ø 150 mm):**
   * **Außenrand:**
     * Roter Taktikpfeil `TRUE WIND` (TWD) bei $0^\circ$.
     * `TACK`-Winkelmarken bei $38{,}0^\circ$ bis $41{,}8^\circ$ beidseitig (optimaler Am-Wind-Wendewinkel).
     * `GYBE`-Winkelmarken bei $142{,}8^\circ$ bis $167{,}5^\circ$ beidseitig (optimaler VMG-Halsewinkel).
   * **Innenfeld:**
     * Vertikale Referenzsehne $L$ des wahren Windes.
     * Symmetrische Schar der Fasskreisbögen ($\Delta\alpha = 2{,}5^\circ$).
     * Vollständige ORC-Polarkurven der J/125 für 9 Windstärken ($4$ bis $24\,\text{kn}$), skaliert mit $4{,}5\,\text{mm/kn}$.
### Seite B: Logarithmischer Performance-Rechner (Rückseite)
1. **Fester Gehäuseboden (Außenring Ø 150 bis 180 mm):**
   * Feste C/D-Logarithmusskala ($1$ bis $10$ bzw. $10$ bis $100\,\text{kn}$).
2. **Mittelscheibe / Rotor (Sichtfenster Ø 150 mm):**
   * Sinus-Skala ($6^\circ$ bis $90^\circ$) am Außenrand.
   * Grüner $100\%$-Target-Indexfluchtzeiger.
   * Prozent-Noniusstriche: $-15\%, -10\%, -5\%, +5\%$.
---
## 5. Vollständige ORC-Polardaten (J/125 Referenzmatrix)

| Parameter / TWA | 4 kn | 6 kn | 8 kn | 10 kn | 12 kn | 14 kn | 16 kn | 20 kn | 24 kn |
| :--- | :--- | :--- | :--- | :--- | :--- | :--- | :--- | :--- | :--- |
| **Beat Angle** | $41{,}8^\circ$ | $41{,}8^\circ$ | $40{,}0^\circ$ | $38{,}5^\circ$ | $38{,}0^\circ$ | $37{,}7^\circ$ | $38{,}1^\circ$ | $38{,}4^\circ$ | $39{,}8^\circ$ |
| **Beat VMG** | $2{,}70$ | $3{,}70$ | $4{,}44$ | $4{,}83$ | $5{,}01$ | $5{,}12$ | $5{,}19$ | $5{,}24$ | $5{,}12$ |
| **Target Beat Speed** | $3{,}62$ | $4{,}96$ | $5{,}80$ | $6{,}17$ | $6{,}36$ | $6{,}47$ | $6{,}60$ | $6{,}69$ | $6{,}66$ |
| **52°** | $4{,}14$ | $5{,}55$ | $6{,}50$ | $6{,}96$ | $7{,}15$ | $7{,}26$ | $7{,}34$ | $7{,}42$ | $7{,}38$ |
| **60°** | $4{,}37$ | $5{,}80$ | $6{,}73$ | $7{,}18$ | $7{,}38$ | $7{,}49$ | $7{,}57$ | $7{,}65$ | $7{,}65$ |
| **75°** | $4{,}52$ | $5{,}96$ | $6{,}87$ | $7{,}36$ | $7{,}64$ | $7{,}80$ | $7{,}92$ | $8{,}08$ | $8{,}16$ |
| **90°** | $4{,}48$ | $5{,}94$ | $6{,}88$ | $7{,}34$ | $7{,}71$ | $7{,}99$ | $8{,}21$ | $8{,}52$ | $8{,}70$ |
| **110°** | $4{,}55$ | $6{,}11$ | $7{,}18$ | $7{,}71$ | $8{,}00$ | $8{,}26$ | $8{,}49$ | $8{,}89$ | $9{,}21$ |
| **120°** | $4{,}42$ | $6{,}00$ | $7{,}11$ | $7{,}72$ | $8{,}20$ | $8{,}54$ | $8{,}83$ | $9{,}38$ | $9{,}94$ |
| **135°** | $3{,}82$ | $5{,}36$ | $6{,}61$ | $7{,}40$ | $7{,}94$ | $8{,}47$ | $9{,}03$ | $10{,}38$ | $11{,}69$ |
| **150°** | $3{,}23$ | $4{,}55$ | $5{,}68$ | $6{,}65$ | $7{,}36$ | $7{,}87$ | $8{,}38$ | $9{,}56$ | $11{,}93$ |
| **Run VMG** | $2{,}79$ | $3{,}94$ | $4{,}92$ | $5{,}76$ | $6{,}49$ | $7{,}07$ | $7{,}55$ | $8{,}49$ | $10{,}33$ |
| **Gybe Angle** | $142{,}8^\circ$ | $142{,}8^\circ$ | $146{,}6^\circ$ | $149{,}8^\circ$ | $157{,}6^\circ$ | $164{,}8^\circ$ | $167{,}5^\circ$ | $165{,}5^\circ$ | $143{,}6^\circ$ |

---
## 6. Vorgaben für die Pipeline (STL & SVG Artefakte)
### 6.1 CAD / 3D-Druck (STL-Dateien)
* `gehaeuse_deckel.stl`: Oberer Haltering mit $2{,}5\,\text{mm}$ Wandstärke, 6 Senkbohrungen M3.
* `gehaeuse_boden.stl`: Unterer Ring mit integrierter Nut ($173{,}0\,\text{mm} \times 2{,}4\,\text{mm}$), 6 M3-Gewindebohrungen.
* `mittelscheibe_rotor.stl`: Drehkörper mit Bund ($\varnothing 172{,}0\,\text{mm} \times 2{,}0\,\text{mm}$) und 4 Rändelsegmenten ($\varnothing 186{,}0\,\text{mm}$).
### 6.2 Laserplotter (SVG-Dateien, maßhaltig 1:1 in Millimetern)
* `laser_seite_a_deckel_kompass.svg`: $360^\circ$-Kompassrose für den Deckelring.
* `laser_seite_a_rotor_polare_fasskreise.svg`: Fasskreise, Polarkurven und Taktik-Pfeile für den Rotor (Vorderseite).
* `laser_seite_b_boden_logskala.svg`: Logarithmische C/D-Skala für den Gehäuseboden.
* `laser_seite_b_rotor_sinus_performance.svg`: Sinusskala und Nonius für den Rotor (Rückseite).
* **Farbkonventionen:**
  * `#FF0000` (Rot, $0{,}15\,\text{mm}$): Vektorschnitt (Ausschneiden / Bohrungen).
  * `#000000` (Schwarz, $0{,}25\,\text{mm}$): Feine Vektorgravur (Skalenstriche, Ziffern).
  * `#2C3E50` / `#C0392B` (Farbig): Sondergravuren (ORC-Kurven, Taktik-Markierungen).

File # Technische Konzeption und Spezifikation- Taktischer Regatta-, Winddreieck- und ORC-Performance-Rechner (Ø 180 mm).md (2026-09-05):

# Technische Konzeption und Spezifikation: Taktischer Regatta-, Winddreieck- und ORC-Performance-Rechner (Ø 180 mm)
## 1. Systemübersicht und Zielsetzung
Das Instrument ist ein analoges, mechanisch gekoppeltes Navigations- und Trimmgerät für den Regatta- und Performance-Einsatz. Es vereint:
1. Einen **Taktikrechner** (Kompassrose vs. Windrichtung zur Bestimmung von Wenden-, Halse- und Bahnmarkenkursen).
2. Ein **geometrisches Fasskreis-Nomogramm** zur direkten Bestimmung des Segeltrimms aus dem scheinbaren Windwinkel $\alpha = \text{AWA}$ über einer festen Basis.
3. Ein zentriertes **ORC-Polardiagramm** zur Visualisierung der Soll-Bootsgeschwindigkeit nach ORC-Messbriefdaten.
4. Einen **logarithmischen Rechenschieber** (C/D-Skala und Performance-%-Skala) auf der Rückseite zur quantitativen Soll-Ist-Geschwindigkeitsanalyse.
Das Gerät wird im 3D-Druck (FDM/SLA) gefertigt und mittels Laserplotter beschriftet und skaliert.
---
## 2. Mechanischer Schichtaufbau (3-Lagen-Kassette)
### 2.1 Führungskonzept
Die Konstruktion verzichtet auf eine zentrale Achsschraube. Die drehbare Mittelscheibe wird über einen umlaufenden Außenbund (Feder) in einer ringförmigen Nut zwischen Gehäusedeckel und Gehäuseboden zentriert und geführt.
### 2.2 Dimensionierung (Nennmaß Ø 180 mm)
* **Gehäusedeckel (Seite A / Oben):**
  * Außendurchmesser: $180{,}0\,\text{mm}$
  * Innenfenster (Sichtbereich): $\varnothing 150{,}0\,\text{mm}$
  * Ringbreite des festen Skalenstegs: $15{,}0\,\text{mm}$
  * Dicke: $2{,}5\,\text{mm}$
  * 6 Senkbohrungen für M3-Schrauben auf Teilkreis $\varnothing 176{,}0\,\text{mm}$
* **Gehäuseboden (Seite B / Unten):**
  * Außendurchmesser: $180{,}0\,\text{mm}$
  * Innenfenster (Sichtbereich): $\varnothing 150{,}0\,\text{mm}$
  * Integrierte Ringnut: Innendurchmesser $173{,}0\,\text{mm}$, Nuttiefe in Z-Richtung $2{,}4\,\text{mm}$
  * 6 Kernlochbohrungen (M3 bzw. Einschmelzgewinde) auf Teilkreis $\varnothing 176{,}0\,\text{mm}$
* **Mittelscheibe (Rotor / Beidseitig opak beschriftet):**
  * Sichtbarer Kernbereich: $\varnothing 150{,}0\,\text{mm}$
  * Führungsbund (Feder): $\varnothing 172{,}0\,\text{mm}$, Dicke $2{,}0\,\text{mm}$
  * 4 symmetrisch angeordnete Rändelsegmente ($30^\circ$ Winkelbreite), die durch radiale Aussparungen des Gehäuses auf einen Durchmesser von $\varnothing 186{,}0\,\text{mm}$ hervorragen ($3\,\text{mm}$ Greifüberstand).
* **Lager- und Fertigungstoleranzen:**
  * Radiales Spiel: $\Delta r = 0{,}5\,\text{mm}$ ($173{,}0\,\text{mm}$ Nut vs. $172{,}0\,\text{mm}$ Bund).
  * Axiales Spiel: $\Delta z = 0{,}4\,\text{mm}$ ($2{,}4\,\text{mm}$ Nuttiefe vs. $2{,}0\,\text{mm}$ Bunddicke).
  * Gravurvertiefung: Beidseitig $0{,}4\,\text{mm}$ plane Absenkung zum Schutz der Lasermarkierung gegen Reibung.
---
## 3. Mathematische und Geometrische Grundlagen
### 3.1 Das Winddreieck über Grund
Es gilt die Vektorgleichung:
$$\vec{v}_{\text{scheinbar}} = \vec{v}_{\text{wahr}} - \vec{v}_{\text{Boot}}$$
bzw.
$$\vec{v}_{\text{wahr}} = \vec{v}_{\text{Boot}} + \vec{v}_{\text{scheinbar}}$$
* $\text{SOG}$: Geschwindigkeit über Grund (Bootsvektor entlang Schiffslängsachse).
* $\text{AWS}$: Scheinbare Windgeschwindigkeit (Apparent Wind Speed).
* $\alpha = \text{AWA}$: Scheinbarer Windwinkel zur Schiffslängsachse (Windfahne).
* $\text{TWS}$: Wahre Windgeschwindigkeit (True Wind Speed).
* $\beta = \text{TWA}$: Wahrer Windwinkel (True Wind Angle).
### 3.2 Geometrie der Fasskreis-Kurvenschar (Option 2: Feste Sehne über wahrem Wind)
* **Basissehne:** Wahre Windrichtung als Einheitsstrecke $L = 1{,}0$ vom Drehzentrum $W_0 (0,0)$ zum Kopfpunkt $W_1 (0, L)$ entlang der $0^\circ$-Achse.
* **Peripheriewinkelsatz:** Alle Punkte $B(x, y)$, an denen der Winkel zwischen Bootsvektor (nach $W_0$) und scheinbarem Windvektor (von $W_1$) exakt $\alpha$ beträgt, liegen auf einem Fasskreis über $W_0 W_1$.
* **Mittelpunkt des Fasskreises für Winkel $\alpha$:**
  $$x_M = \pm \frac{L}{2} \cot(\alpha), \quad y_M = \frac{L}{2}$$
  *(Plus für Steuerbordbug, Minus für Backbordbug).*
* **Radius des Fasskreises:**
  $$R_\alpha = \frac{L}{2 \sin(\alpha)}$$
* **Schrittweite:** $\Delta\alpha = 2{,}5^\circ$ im Bereich von $20^\circ \le \alpha \le 160^\circ$.
### 3.3 Logarithmische Rechenskalen (C/D- und S-Skala)
Auf der Rückseite gilt für die $360^\circ$-Winkelabbildung einer Dekade ($1$ bis $10$ bzw. $10$ bis $100\,\text{kn}$):
* **Geschwindigkeitsskala:** $\varphi_v = 360^\circ \cdot \log_{10}(v)$
* **Sinusskala:** $\varphi_\theta = 360^\circ \cdot \log_{10}(\sin(\theta))$
* **Prozentskala (Performance):**
  $$\Delta\varphi = 360^\circ \cdot \log_{10}\left(\frac{\text{SOG}}{\text{Target SOG}}\right)$$
  Eine Abweichung von $-5\%$ entspricht $-8{,}0^\circ$, $-10\%$ entspricht $-16{,}5^\circ$, $+5\%$ entspricht $+7{,}6^\circ$.
---
## 4. Skalenbelegung und Gravur-Architektur
### 4.1 Seite A: Taktik- und Trimm-Rechner (Vorderseite)
#### Fester Gehäusedeckel (Außenring Ø 150 bis 180 mm)
* Gravur einer vollständigen **$360^\circ$-Kompassrose**:
  * Hauptteilungen alle $10^\circ$, Mittelteilstriche alle $5^\circ$, Einzelstriche alle $1^\circ$.
  * Bezifferung alle $30^\circ$ ($000^\circ, 030^\circ, 060^\circ, \dots, 330^\circ$).
#### Rotierende Mittelscheibe (Sichtfenster Ø 150 mm)
* **Außenrand ($\varnothing 142$ bis $150\,\text{mm}$):**
  * Taktischer Windpfeil **TRUE WIND** bei $0^\circ$.
  * **Beat Angle Indikatoren (Upwind Target Marks):** Markierungen bei $37{,}7^\circ$ bis $41{,}8^\circ$ beidseitig (Stb/Bb).
  * **Gybe Angle Indikatoren (Downwind VMG Marks):** Markierungen bei $142{,}8^\circ$ bis $167{,}5^\circ$ beidseitig (Stb/Bb).
* **Zentralbereich ($\varnothing 0$ bis $140\,\text{mm}$):**
  * **ORC-Polarkurven** für die 9 Windstärken ($4, 6, 8, 10, 12, 14, 16, 20, 24\,\text{kn}$).
  * **Fasskreis-Kurvenschar** mit $\Delta\alpha = 2{,}5^\circ$, hervorgehoben alle $10^\circ$.
### 4.2 Seite B: Logarithmischer Performance-Rechner (Rückseite)
#### Fester Gehäuseboden (Außenring Ø 150 bis 180 mm)
* Feste logarithmische **C/D-Geschwindigkeitsskala** für Knoten:
  * Bereich: $1$ bis $30\,\text{kn}$ (bzw. $1$ bis $10$ mit Dekadenumrechnung).
#### Rotierende Mittelscheibe (Sichtfenster Ø 150 mm)
* **Sinusskala (S-Skala):** Winkel von $6^\circ$ bis $90^\circ$.
* **Performance-%-Nonius:**
  * $100\%$-Indexmarke (fluchtend mit der Soll-Geschwindigkeit).
  * Abweichungsstriche für $-15\%, -10\%, -5\%, 0\%, +5\%$.
---
## 5. Eingebundene ORC-Leistungsdaten (Referenztabelle)
Die folgenden Messbriefdaten liegen den Polarkurven und Taktikmarken zugrunde:

| Parameter / TWA | 4 kn | 6 kn | 8 kn | 10 kn | 12 kn | 14 kn | 16 kn | 20 kn | 24 kn |
| :--- | :--- | :--- | :--- | :--- | :--- | :--- | :--- | :--- | :--- |
| **Beat Angle** | $41{,}8^\circ$ | $41{,}8^\circ$ | $40{,}0^\circ$ | $38{,}5^\circ$ | $38{,}0^\circ$ | $37{,}7^\circ$ | $38{,}1^\circ$ | $38{,}4^\circ$ | $39{,}8^\circ$ |
| **Beat VMG** | $2{,}70$ | $3{,}70$ | $4{,}44$ | $4{,}83$ | $5{,}01$ | $5{,}12$ | $5{,}19$ | $5{,}24$ | $5{,}12$ |
| **Target Beat Speed** | $3{,}62$ | $4{,}96$ | $5{,}80$ | $6{,}17$ | $6{,}36$ | $6{,}47$ | $6{,}60$ | $6{,}69$ | $6{,}66$ |
| **$52^\circ$** | $4{,}14$ | $5{,}55$ | $6{,}50$ | $6{,}96$ | $7{,}15$ | $7{,}26$ | $7{,}34$ | $7{,}42$ | $7{,}38$ |
| **$60^\circ$** | $4{,}37$ | $5{,}80$ | $6{,}73$ | $7{,}18$ | $7{,}38$ | $7{,}49$ | $7{,}57$ | $7{,}65$ | $7{,}65$ |
| **$75^\circ$** | $4{,}52$ | $5{,}96$ | $6{,}87$ | $7{,}36$ | $7{,}64$ | $7{,}80$ | $7{,}92$ | $8{,}08$ | $8{,}16$ |
| **$90^\circ$** | $4{,}48$ | $5{,}94$ | $6{,}88$ | $7{,}34$ | $7{,}71$ | $7{,}99$ | $8{,}21$ | $8{,}52$ | $8{,}70$ |
| **$110^\circ$** | $4{,}55$ | $6{,}11$ | $7{,}18$ | $7{,}71$ | $8{,}00$ | $8{,}26$ | $8{,}49$ | $8{,}89$ | $9{,}21$ |
| **$120^\circ$** | $4{,}42$ | $6{,}00$ | $7{,}11$ | $7{,}72$ | $8{,}20$ | $8{,}54$ | $8{,}83$ | $9{,}38$ | $9{,}94$ |
| **$135^\circ$** | $3{,}82$ | $5{,}36$ | $6{,}61$ | $7{,}40$ | $7{,}94$ | $8{,}47$ | $9{,}03$ | $10{,}38$ | $11{,}69$ |
| **$150^\circ$** | $3{,}23$ | $4{,}55$ | $5{,}68$ | $6{,}65$ | $7{,}36$ | $7{,}87$ | $8{,}38$ | $9{,}56$ | $11{,}93$ |
| **Run VMG** | $2{,}79$ | $3{,}94$ | $4{,}92$ | $5{,}76$ | $6{,}49$ | $7{,}07$ | $7{,}55$ | $8{,}49$ | $10{,}33$ |
| **Gybe Angle** | $142{,}8^\circ$ | $142{,}8^\circ$ | $146{,}6^\circ$ | $149{,}8^\circ$ | $157{,}6^\circ$ | $164{,}8^\circ$ | $167{,}5^\circ$ | $165{,}5^\circ$ | $143{,}6^\circ$ |

---
## 6. Bedienungsabläufe an Bord
### 6.1 Taktischer Kursabgleich (Pre-Start / Upwind)
1. Die gemessene wahre Windrichtung (TWD, z. B. $240^\circ$) wird eingestellt, indem der Pfeil **TRUE WIND** der Mittelscheibe auf $240^\circ$ der festen Kompassrose gedreht wird.
2. Der Steuerkurs am Wind auf Steuerbordbug wird an der Beat-Marke abgelesen: $240^\circ + 38^\circ = 278^\circ$.
3. Der Kurs nach einer Wende auf Backbordbug steht direkt an der gegenüberliegenden Beat-Marke: $240^\circ - 38^\circ = 202^\circ$.
4. Dreht der Wind (z. B. auf $245^\circ$), wird die Scheibe um $5^\circ$ nachgeführt; alle neuen Anliegelinien zu Luv- und Leetonnen sind sofort ersichtlich.
### 6.2 Performance- und Trimmkontrolle (Szenario 2)
1. Der Steuermann hält das Schiff nach Windfahne auf scheinbarem Windwinkel $\alpha = 38^\circ$.
2. Der Navigator blickt auf den $38^\circ$-Fasskreisbogen und sucht den Schnittpunkt mit der aktuellen Windkurve (z. B. $12\,\text{kn}$).
3. **Ergebnis:** Die Soll-Geschwindigkeit beträgt $6{,}36\,\text{kn}$.
4. Auf Seite B wird die $100\%$-Marke auf $6{,}36\,\text{kn}$ gelegt. Der tatsächliche GPS-Wert ($6{,}0\,\text{kn}$) zeigt direkt auf der Prozentskala: **$-5{,}7\%$ Unterperformance**.
---
## 7. Fertigungsspezifikation
### 7.1 3D-Druck (FDM / SLA)
* **Material:** PETG, ASA oder ABS (UV- und salzwasserbeständig, formstabil bis $>70^\circ\text{C}$).
* **Schichthöhe:** $0{,}15\,\text{mm}$ bis $0{,}20\,\text{mm}$ (Glättung der Skalenbetten per "Ironing" / Bügeln empfohlen).
* **Infill:** Mindestens $30\%$ gyroidal für hohe Verwindungssteifigkeit.
* **Farbe:** Helles Weiß oder Hellgrau als Kontrastgrund für die Lasergravur.
### 7.2 Laserbeschriftung (CO2- oder Faserlaser)
* **Farbcodierung in den Vektordateien (SVG):**
  * `Rot (#FF0000)`: Vektorschnitt (Cut lines).
  * `Schwarz (#000000)`: Feine Liniengravur (Skalenstriche, Fasskreise, Ziffern).
  * `Blau (#0000FF)`: Vektor-Schraffur / Ausfüllung (ORC-Kurven, Pfeile).

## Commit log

2026-08-30 Initial commit: Nautische Rechenscheibe & Taktik-Suite JPK 1080 (GER 7447)
    [GER7447_polars.csv, J125.xlsx, laser_lineal.dxf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]
2026-08-30 docs: Ausführliche Dokumentation der Rechenscheibe, Physik, 3D-Druck, Laser und Taktik-Suite
2026-08-30 feat: Doppelseitige Rechenscheibe mit zentralem Ratio-Zeiger und rotierendem Rechenschieber auf der Rückseite
    [laser_rotor_rueckseite.dxf, laser_rotor_vorderseite.dxf, laser_stator_aussenring.dxf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]
2026-08-30 fix: Nautische Ausrichtung (Polaren aufrecht, 0° oben), vollständige AWA-Skala und dichte Rechenschieber-Teilung
    [laser_rotor_rueckseite.dxf, laser_rotor_vorderseite.dxf, laser_stator_rueckseite.dxf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]
2026-08-30 feat: Echte AWA-Fasskreisbögen auf Vorderseite und Sinus-Skala (S-Skala) auf Rückseite implementiert
    [laser_rotor_rueckseite.dxf, laser_rotor_vorderseite.dxf, laser_stator_rueckseite.dxf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]
2026-09-05 feat: Release V1.0 - 180mm Sandwich-Rechenscheibe JPK 1080 (GER 7447) mit TackingMaster-Taktikring, STL- & SVG-Fertigungssuite
    [achspin_mittelbolzen.stl, gehaeuse_boden_180mm.stl, gehaeuse_deckel_180mm.stl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]
2026-09-05 feat: Release V1.1 - Enlarged inward S-scale (R=63mm) and back-side cursor pointer
    [achspin_mittelbolzen.stl, zentralzeiger_rueckseite.stl]
2026-09-06 feat: Release V1.11 - Refined polar scales, inward stator rose, symmetric beat labels, enlarged S-scale (R=65mm)
2026-09-06 feat: Release V1.20 - Parametrische Konfiguration, Single Source of Truth SVG->PNG, cmath Vektorgeometrie, Statorrose außen
    [achspin_mittelbolzen.stl, gehaeuse_boden_180mm.stl, gehaeuse_deckel_180mm.stl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]
2026-09-08 feat: Release V3.0 - 1:1 ORC-Polaren (TWA/AWA), radiale S-Skala, Bambu-optimierte STLs mit 1mm Zentrierbohrungen und modulare Config
    [gehaeuse_boden_180mm.stl, gehaeuse_deckel_180mm.stl]
2026-09-08 docs: Aktualisiere Abbildungen in README auf V3.0 (1mm Zentrierbohrungen, Rotor-Detailansicht, Hero-Banner, Cache-Busting)
2026-09-08 fix: Nahtloser 180°-Polarenübergang (TWA/AWA) und Behebung des Speed-Guide-Versatzes
2026-09-08 docs: Übergabe- und Statusdokumentation context.md hinzugefügt
